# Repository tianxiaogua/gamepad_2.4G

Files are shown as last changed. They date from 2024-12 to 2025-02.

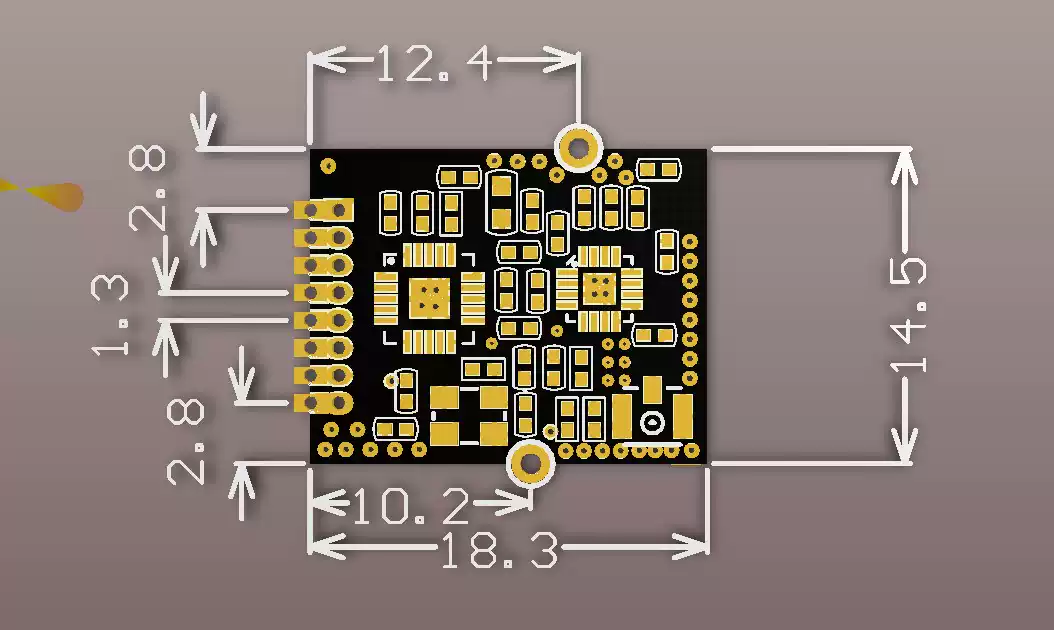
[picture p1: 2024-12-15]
doc/GT24-MINI.webp

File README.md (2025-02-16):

[TOC]

# 参考：

[joystick usb配置描述符 - 哔哩哔哩](https://www.bilibili.com/opus/961840479809306630)

[USB手柄Jostick开发 HID设备 STM32CubeIDE软件使用HAL库教程 STM32F042模块_哔哩哔哩_bilibili](https://www.bilibili.com/video/BV1kv4y1U7a9/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)

# 软件

# 硬件

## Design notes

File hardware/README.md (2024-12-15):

# V1.1 LOG 2024.4.10



## 设计实现

1、首版硬件主要实现了双USB，前面的是ESP32 USB，后面的USB用于调试；

2、实现基础的ESP32外围电路、下载电路、按键周围电路；

3、验证了摇杆封装；

4、为了实现更多的设备链接，增加了NRF2401模块用于实现2.4G射频前端；

5、增加了蜂鸣器；

6、电源部分使用3.7V升压方案，升压到稳定的5V，再降压到3.3V给系统电源使用；

7、可连接一块2.4寸TFT lCD屏幕；

8、确定了PCB形状和遥控器外形3D；

## 存在问题

1、前后两个USB过于累赘，下版本设计USB HUB芯片连接到一个USB口；

2、按键的手感不好，需要更改按键选型；

# V1.2 LOG 2024 6.22



## 设计实现

1、重新设计了按键选型；

2、添加USB HUB芯片可以是实现两个USB连接在一个USB口上；

3、增加了IO拓展芯片。

## 存在问题

1、2.4G通信模组实际使用中属于实际冗余，下一个版本需要去掉；

2、USB上拉引脚接错了，需要接在USB DP上；

3、IO拓展芯片的最好上拉值应设置在4.7K；

4、按键的引脚分配存在问题，不可以使用ESP32的某些引脚，下版本将这些引脚重新设置到IO拓展引脚上，部分引脚需要重新分配；

5、屏幕的位置比较难安装，屏幕排线需要延长，需要单独设计一块延长排线的转接板；

# V1.3 LOG 2024.8.18



## 设计实现

1、增加陀螺仪加速器芯片；

2、增加两个肩键在扫描电路上、增加CHA按键连接在ESP32 IO；

3、开机电路增加EN排针插座；

4、增加接收电路部分和排线电路；

5、重新布局布线；

## 存在问题

1、SPI1_CS放在IO拓展芯片上会降低SPI 通信速度，下版本将SPI1_CS 换到ESP32 GPIO7 ，将原本USB KEY换到 IO 拓展引脚；

2、KEY_SELECT和KEY_START按键的外部电路错误，下一版本需要将IO引脚上拉，按键另一端连接到GND；

3、MPU6050上拉电阻修改至2K；

4、PCA9557 IIC上拉修改至2K，IO0上拉修改至4.7K；

# V1.3.1 LOG 2024.8.29



## 设计实现

1、修改按键上拉和接地；

2、调换key_usb和SPI_CS引脚；

## 存在问题

1. CH340芯片电源部分使用3.3V；
2. flash芯片统一使用8M W25Q64；
3. 调整升压芯片输出，小于4.8V 使用反馈电阻换为69.8K；
4.

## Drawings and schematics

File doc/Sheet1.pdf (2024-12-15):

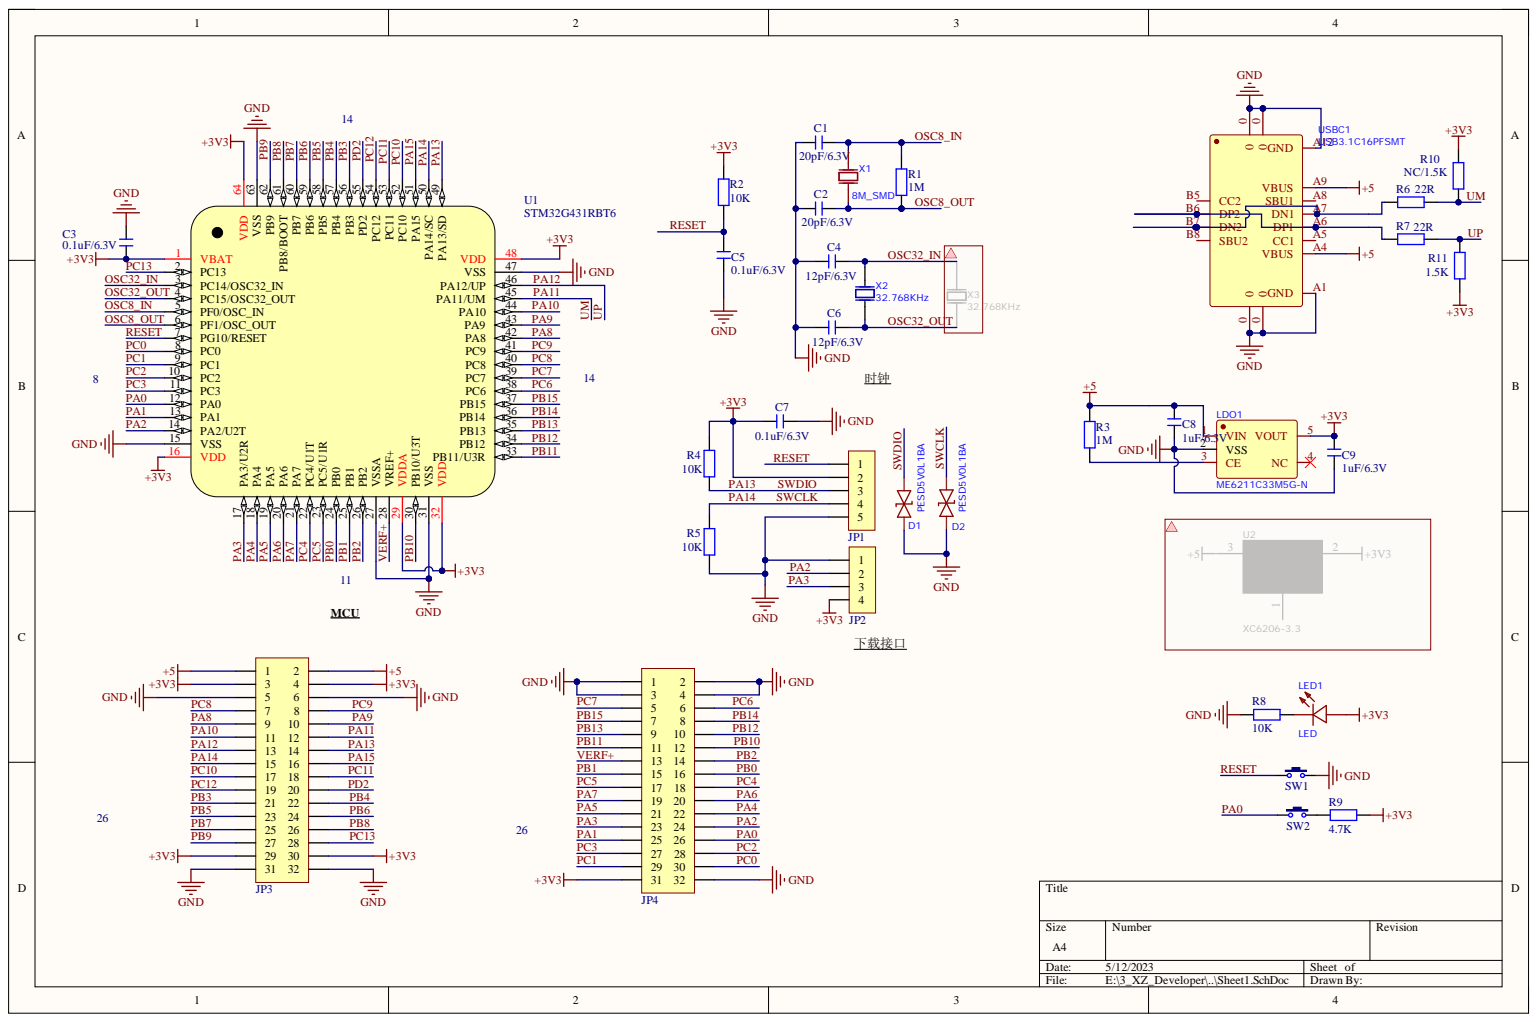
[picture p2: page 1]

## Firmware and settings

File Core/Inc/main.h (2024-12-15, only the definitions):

#define LED0_Pin GPIO_PIN_13
#define LED0_GPIO_Port GPIOC
#define ADC_RY_Pin GPIO_PIN_0
#define ADC_RY_GPIO_Port GPIOC
#define ADC_RX_Pin GPIO_PIN_1
#define ADC_RX_GPIO_Port GPIOC
#define BEEP_Pin GPIO_PIN_2
#define BEEP_GPIO_Port GPIOC
#define LCD_RS_Pin GPIO_PIN_3
#define LCD_RS_GPIO_Port GPIOC
#define KEY_CHA_Pin GPIO_PIN_0
#define KEY_CHA_GPIO_Port GPIOA
#define ADC_LX_Pin GPIO_PIN_1
#define ADC_LX_GPIO_Port GPIOA
#define ADC_LY_Pin GPIO_PIN_2
#define ADC_LY_GPIO_Port GPIOA
#define ADC_BAT_Pin GPIO_PIN_3
#define ADC_BAT_GPIO_Port GPIOA
#define GT_24_IRQ_Pin GPIO_PIN_4
#define GT_24_IRQ_GPIO_Port GPIOA
#define GT_24_CSN_Pin GPIO_PIN_4
#define GT_24_CSN_GPIO_Port GPIOC
#define GT_24_CE_Pin GPIO_PIN_5
#define GT_24_CE_GPIO_Port GPIOC
#define KEY_DOWN_1_Pin GPIO_PIN_10
#define KEY_DOWN_1_GPIO_Port GPIOB
#define KEY_DOWN_2_Pin GPIO_PIN_11
#define KEY_DOWN_2_GPIO_Port GPIOB
#define KEY_DOWN_3_Pin GPIO_PIN_12
#define KEY_DOWN_3_GPIO_Port GPIOB
#define KEY_up_Pin GPIO_PIN_6
#define KEY_up_GPIO_Port GPIOC
#define KEY_down_Pin GPIO_PIN_7
#define KEY_down_GPIO_Port GPIOC
#define KEY_left_Pin GPIO_PIN_8
#define KEY_left_GPIO_Port GPIOC
#define KEY_right_Pin GPIO_PIN_9
#define KEY_right_GPIO_Port GPIOC
#define POWER_EN_Pin GPIO_PIN_8
#define POWER_EN_GPIO_Port GPIOA
#define MPU_INT_Pin GPIO_PIN_10
#define MPU_INT_GPIO_Port GPIOC
#define KEY_USB_Pin GPIO_PIN_11
#define KEY_USB_GPIO_Port GPIOC
#define KEY_select_Pin GPIO_PIN_12
#define KEY_select_GPIO_Port GPIOC
#define KEY_start_Pin GPIO_PIN_2
#define KEY_start_GPIO_Port GPIOD
#define LCD_LEDA_Pin GPIO_PIN_3
#define LCD_LEDA_GPIO_Port GPIOB
#define KEY_1_Pin GPIO_PIN_4
#define KEY_1_GPIO_Port GPIOB
#define kEY_2_Pin GPIO_PIN_5
#define kEY_2_GPIO_Port GPIOB
#define SPI2_CS0_Pin GPIO_PIN_6
#define SPI2_CS0_GPIO_Port GPIOB
#define LCD_REST_Pin GPIO_PIN_9
#define LCD_REST_GPIO_Port GPIOB

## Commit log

2024-12-15 首次提交，首版PCB，基础cubemx驱动
    [PCB.PcbDoc, Sheet0-mcu.SchDoc, Sheet1-control.SchDoc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]
2025-02-16 更新硬件，替换软件到STM32F103RCT6
    [Sheet0-mcu.SchDoc, Sheet1-control.SchDoc, Sheet2-USB.SchDoc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]

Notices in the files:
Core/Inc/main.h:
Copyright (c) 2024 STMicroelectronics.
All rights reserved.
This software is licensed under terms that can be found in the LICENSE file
